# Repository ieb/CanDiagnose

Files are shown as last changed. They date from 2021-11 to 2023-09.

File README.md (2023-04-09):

# Can Diagnose

Runs on a ESP32 with a webserver exposing an API to diagnose and monitor CanBus traffic.
Based on Datadisplay and DeviceAnalyser from the NMEA2000 libraries.

* [x] Setup Wifi
* [x] Setup MDNS registration
* [x] Implement webserver
* [x] Serve files from Flash (SPIFFS)
* [x] Implement data api /api/data/<n> where n == 0-10.
* [x] Expose set of standard CAN messages on /api/data
* [x] Implement simple UI in Javascript hosted on SPIFFS, targetting eink and normal browsers (based on SignalK eink)
* [x] Implement BPM280 source
* [x] Implement calibration mechanism using DAC
* [Fail] Implement ADC Source

The ESP32 ADC source cannot be made reliable enough or accurate enough to be used to monitor a battery. 
It is possible to get down to a 0.2% error with a callibrated lookup table, however the ADC mechamism (Sucessive Aproximation Register)
produced noisy values that are frequetly as much as +- 3%. At 12.6v this is 0.4v which is unworkable. Offsetting the voltage with a precision opamp so the ESP32 reads from 11 to 15v would reduce this to 0.15v, however this is still to large to be usable. Multi sampling helps generate a stable reading, however this requires 64 samples with a /5 moving average so over at least 60s. This does give and acceptable accuracy, but the speed of measuring the voltage is close to unworkable.

All attenuations were tried, and 1,2,4,16,32,64 clock divisions were tried to see if the rate of the SAR made any difference. It does not appear to change the results.

On that basis, I am giving up on using the ESP32 ADC for this purpose.

It still provides a good platform for a Wifi data server, and Can reader.

* [x] Redesign PCB to use 16bit ADC over i2c  (ADS1115)
* [x] Implement ADC sensor code.  
* [x] Implement admin interface.
* [x] Support configuration and calibration via web browser.
* [x] Support Configuraiton of single and differential ADC.
* [x] Add OLED display 
* [x] Add touch sensor to control oled display
* [x] Bench Calibrate expecialy shunt
* [x] Install test and calibrate. - Failed, the distance beween the board and the batteries is too great to get reliable shunt measurements.
* [x] Investigate using a shunt amplifier as used by VRA Alternator controll
* [x] Implement remote battery sensor using Modbus  (see BatterySensor project)
* [x] Reimplement PCB to have no BME280 and no ADS1115 replacing with a RS485 interface to ModBus devices.  (see CanPressure for Can based pressure, humidity, temperature sensor)
* [x] Implement Modbus master

# Usage

The device will boot and connect to wifi controlled by its burned in config file (data/config.txt). 
There are 2 modes it can run in, a WiFi client or a AP. If its configured to be an AP, then join its network. If its a client find its ip. From now on this will be <ip>

Go to its ip on http://<ip> and you will see a data view of the data it is capturing.
Go to http://<ip>/admin.html and you will see a admin view with the ability to upload a new configuration file and reboot.

Both these views ae SPAs served from static files burned into the ESP32 Flash using APIs.

Connecting to the serial port monitor allows lower level control and diagnostics, enter 'h<CR>' to get help.

# Developing

Project uses PlatformIO in VSCode.  WebUI is in  ui/einkweb with build files added to data/ to be built into a flash image using ./buidui.sh

## PIO commands

because I alwaysforget.

* pio run -t upload
* pio device monitor

See buildui.sh for SPIFFS image commands.

# Connectors

    ---------------------------------------------
    |           a b c d e f g h                 |
    |  A                                        |
    |  B                                        |
    |  C                                        |
    |  D                                     H  |
    |  E                                     I  |
    |  F                                     J  |
    |  G           i j k l m                 K  |
    ---------------------------------------------

    a  SPI BL   GPIO13
    b  SPI RST  GPIO12
    c  SPI DC   GPIO26
    d  SPI CS   GPIO25
    e  SPI SCK  GPIO33
    f  SPI MOSI GPIO32
    g  SPI GND  
    h  SPI 3V    
    i  i2c GND      Display black/blue
    j  i2c SCL  D5    Display green
    k  i2c SDA  D18    Display white
    l  i2c BTN  D19    Display yellow
    m  i2c 3V       Display red

    A  1wire 1w  D21
    B  1wire GND
    C  1wire 3V
    D  RS-485 5.8V
    E  RS-485 GND
    F  RS-485 A 
    G  RS-485 B
    H  CAN 12V
    I  CAN 0V
    J  CAN CANH
    K  CAN CANL

    Other Pins Not mentioned above
    RS485-TX TX2/GPIO17
    RS485-RX RX2/GPIO16
    RS485-EN D4
    CAN-RX  D22
    CAN-TX  D23

# eInk Waveshare display

This uses SPI output only with a bunch of additional pins.

    eInk DIN <-  f  SPI MOSI GPIO32
    eInk CLK <-  e  SPI SCK  GPIO33
    eInk CS  <-  d  SPI CS   GPIO25
    eInk DC  <-  c  SPI DC   GPIO26
    eInk RST <-  b  SPI RST  GPIO12
    eInk BUSY -> a  SPI BL   GPIO13

# 4 inch TFT display 480x320 24 bit colour driven by a ILI9488 driver.

uses SPI + a PWM blacklight. Control via a TPP233 Touch switch. Library is TFT_eSPI library. Pin mappings defined as compile definitions.

    -D TFT_MISO=GPIO_NUM_35
    -D TFT_MOSI=GPIO_NUM_32
    -D TFT_SCLK=GPIO_NUM_33
    -D TFT_CS=GPIO_NUM_25
    -D TFT_DC=GPIO_NUM_26
    -D TFT_RST=GPIO_NUM_27
    -D TFT_PWM_BL=GPIO_NUM_14
    -D ILI9488_DRIVER

The display sleeps after 60s of inactivity to reduce power drain, but turning off the backlight. Sleeping the IMI9488 driver has not been done as of yet.  Pages are implemented as classes using widgets. When a page is selected it is allocated into heap and does not exist while not displaying. On other drivers here all pages were compiled in, however the RAM usage is higher on account of full colour and display size. 

In most cases attempts to update the screen, on screen causes flickering so double buffering of updates is done using sprits with DMA transfers from the sprite to the screen. Images for screen are stored in jpg on flash, consuming about 30KB per screen.

Drawing to sprites also works in 1bpp, 4bpp or 16bpp.

## TFT case

3d printed case, with 2 touch sensors and round shielded cable, as ribbon will emit too much interference to nearby devices. 

Wires

|| color || designation || ESP32 Pin ||
---------------------------------------
| Red    |  5v          | 5v           |
| black  |  0v          | 0v           |
| pink   |  CS          | GPIO_NUM_25  |
| cyan   |  Reset       | GPIO_NUM_27  |
| white  |  DC/RS       | GPIO_NUM_26  |
| blue   |  SDI(MOSI)   | GPIO_NUM_32  |
| green  |  SCK         | GPIO_NUM_33  |
| grey   |  LED         | GPIO_NUM_14  |
| Purple |  SDO(MISO)   | GPIO_NUM_35  |
| Orange |  3.3v        | 3.3v         |
| Brown  | Touch Lower  | GPIO_NUM_19  |
| Yellow | Touch Top    | TBD          |

Due to the additional touch pins a fresh PCB is probably needed.

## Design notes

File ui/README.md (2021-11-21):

# UIs

Here are a variety of UIs that are burned into the firmware.
They all use the http API to fetch data from the ESP32 once loaded, defined in swagger.yaml in this directory.

# einkweb

Is a minimal eink browser implementation targetting Generation 1 Kindle devices, but also works on modern browsers and Andriod.

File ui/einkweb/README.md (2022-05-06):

# eink UI 

Based on the UI code used for Eink Signal K, but modified for this firmware and simplified.

# Current state

* Multiple pages
* Landscape and Portrate
* min, max, mean, standard deviation
* linear and circular stats
* Themes, night, day, red, green

# developing

Local server, run  npx http-server and use index_debug.html to load data from a running ESP32 device on the same network.

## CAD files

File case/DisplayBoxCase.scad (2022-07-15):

$fn=100;
module board() {
    difference() {
    union() {
        cube([75,59,3], center=true);
        translate([-32,-4,6])
        cube([8,41,12], center=true);
        translate([32,-12,6])
        cube([8,25,12], center=true);
        translate([0,14,8])
        cube([55,28,21], center=true);
        translate([20,-18,-8])
        cylinder(d=8,h=8);
    }
    translate([-(75/2)+4.5,-(59/2)+3,0])
    cylinder(d=4,h=10,center=true);
    translate([-(75/2)+6.2,(59/2)-6.5,0])
    cylinder(d=4,h=10,center=true);
    translate([(75/2)-4.6,(59/2)-4.7,0])
    cylinder(d=4,h=10,center=true);
    translate([(75/2)-4.6,-(59/2)+3.3,0])
    cylinder(d=4,h=10,center=true);
    }
}

module lid(w=110,d=70,h=15,hb=20,t=3) {
            translate([0,0,hb-t+1]) 
      difference() {
        union() {
            difference() {
                union() {
                    cube([w-t*2,d,h], center=true);
                    cube([w,d-t*2,h], center=true);
                    translate([w/2-t,d/2-t,0])
                    cylinder(r=t,h=h, center=true);
                    translate([-(w/2-t),d/2-t,0])
                    cylinder(r=t,h=h, center=true);
                    translate([-(w/2-t),-(d/2-t),0])
                    cylinder(r=t,h=h, center=true);
                    translate([w/2-t,-(d/2-t),0])
                    cylinder(r=t,h=h, center=true);
                    

                }
                // inside
                translate([0,0,-t*1.5])
                    cube([w-t*2,d-t*2,h+t], center=true);
            translate([0,0,-hb+t]) 
                cables();
            }
            // pillars
            translate([0,0,-hb+t]) {
            translate([-(75/2)+4.5,-(59/2)+3,0])
                union() {
                    cylinder(d=6,h=24);
                }
            translate([-(75/2)+6.2,(59/2)-6.5,0])
                union() {
                    cylinder(d=6,h=24);
                }
            translate([(75/2)-4.6,(59/2)-4.7,0])
                union() {
                    cylinder(d=6,h=24);
                }
            translate([(75/2)-4.6,-(59/2)+3.3,0])
                union() {
                    cylinder(d=6,h=24);
                }
            }
            // fxings
            translate([w/2-2*t,d/2-2*t,0])
                    cylinder(r=5,h=h, center=true);
            translate([-(w/2-2*t),d/2-2*t,0])
                    cylinder(r=5,h=h, center=true);
            translate([-(w/2-2*t),-(d/2-2*t),0])
                    cylinder(r=5,h=h, center=true);
                    translate([w/2-2*t,-(d/2-2*t),0])
                    cylinder(r=5,h=h, center=true);
        }
        
            translate([w/2-2*t,d/2-2*t,0])
                    cylinder(d=3,h=h+10, center=true);
            translate([-(w/2-2*t),d/2-2*t,0])
                    cylinder(d=3,h=h+10, center=true);
            translate([-(w/2-2*t),-(d/2-2*t),0])
                    cylinder(d=3,h=h+10, center=true);
                    translate([w/2-2*t,-(d/2-2*t),0])
                    cylinder(d=3,h=h+10, center=true);
    }
}

module case(w=110,d=70,h=20,t=3) {
      difference() {
        union() {
            difference() {
                union() {
                    cube([w-t*2,d,h], center=true);
                    cube([w,d-t*2,h], center=true);
                    translate([w/2-t,d/2-t,0])
                    cylinder(r=t,h=h, center=true);
                    translate([-(w/2-t),d/2-t,0])
                    cylinder(r=t,h=h, center=true);
                    translate([-(w/2-t),-(d/2-t),0])
                    cylinder(r=t,h=h, center=true);
                    translate([w/2-t,-(d/2-t),0])
                    cylinder(r=t,h=h, center=true);
                    

                }
                // inside
                translate([0,0,t])
                    cube([w-t*2,d-t*2,h+t], center=true);
                cables();
            }
            // pillars
            translate([0,0,-h/2+t/2]) {
            translate([-(75/2)+4.5,-(59/2)+3,0])
                union() {
                    cylinder(d=6,h=7);
                    cylinder(d=3,h=9);
                }
            translate([-(75/2)+6.2,(59/2)-6.5,0])
                union() {
                    cylinder(d=6,h=7);
                    cylinder(d=3,h=9);
                }
            translate([(75/2)-4.6,(59/2)-4.7,0])
                union() {
                    cylinder(d=6,h=7);
                    cylinder(d=3,h=9);
                }
            translate([(75/2)-4.6,-(59/2)+3.3,0])
                union() {
                    cylinder(d=6,h=7);
                    cylinder(d=3,h=9);
                }
            }
            // fxings
            translate([w/2-2*t,d/2-2*t,0])
                    cylinder(r=5,h=h, center=true);
            translate([-(w/2-2*t),d/2-2*t,0])
                    cylinder(r=5,h=h, center=true);
            translate([-(w/2-2*t),-(d/2-2*t),0])
                    cylinder(r=5,h=h, center=true);
                    translate([w/2-2*t,-(d/2-2*t),0])
                    cylinder(r=5,h=h, center=true);
        }
        
            translate([w/2-2*t,d/2-2*t,0])
                    cylinder(d=3,h=h+10, center=true);
            translate([-(w/2-2*t),d/2-2*t,0])
                    cylinder(d=3,h=h+10, center=true);
            translate([-(w/2-2*t),-(d/2-2*t),0])
                    cylinder(d=3,h=h+10, center=true);
                    translate([w/2-2*t,-(d/2-2*t),0])
                    cylinder(d=3,h=h+10, center=true);
    }

}
module cables() {
        translate([-90,-15,10])
    rotate([0,90,0])
    cylinder(d=4,h=90);
    translate([-90,15,10])
    rotate([0,90,0])
    cylinder(d=4,h=90);

    translate([-90,0,10])
    rotate([0,90,0])
    cylinder(d=4,h=90);

    translate([0,-15,10])
    rotate([0,90,0])
    cylinder(d=7,h=90);
}

/*
difference() {
    union() {
        //board();
        case();
        lid();
          //cables();
    }
    cube([65,160,140], center=true);
}
*/

case();
//replid();

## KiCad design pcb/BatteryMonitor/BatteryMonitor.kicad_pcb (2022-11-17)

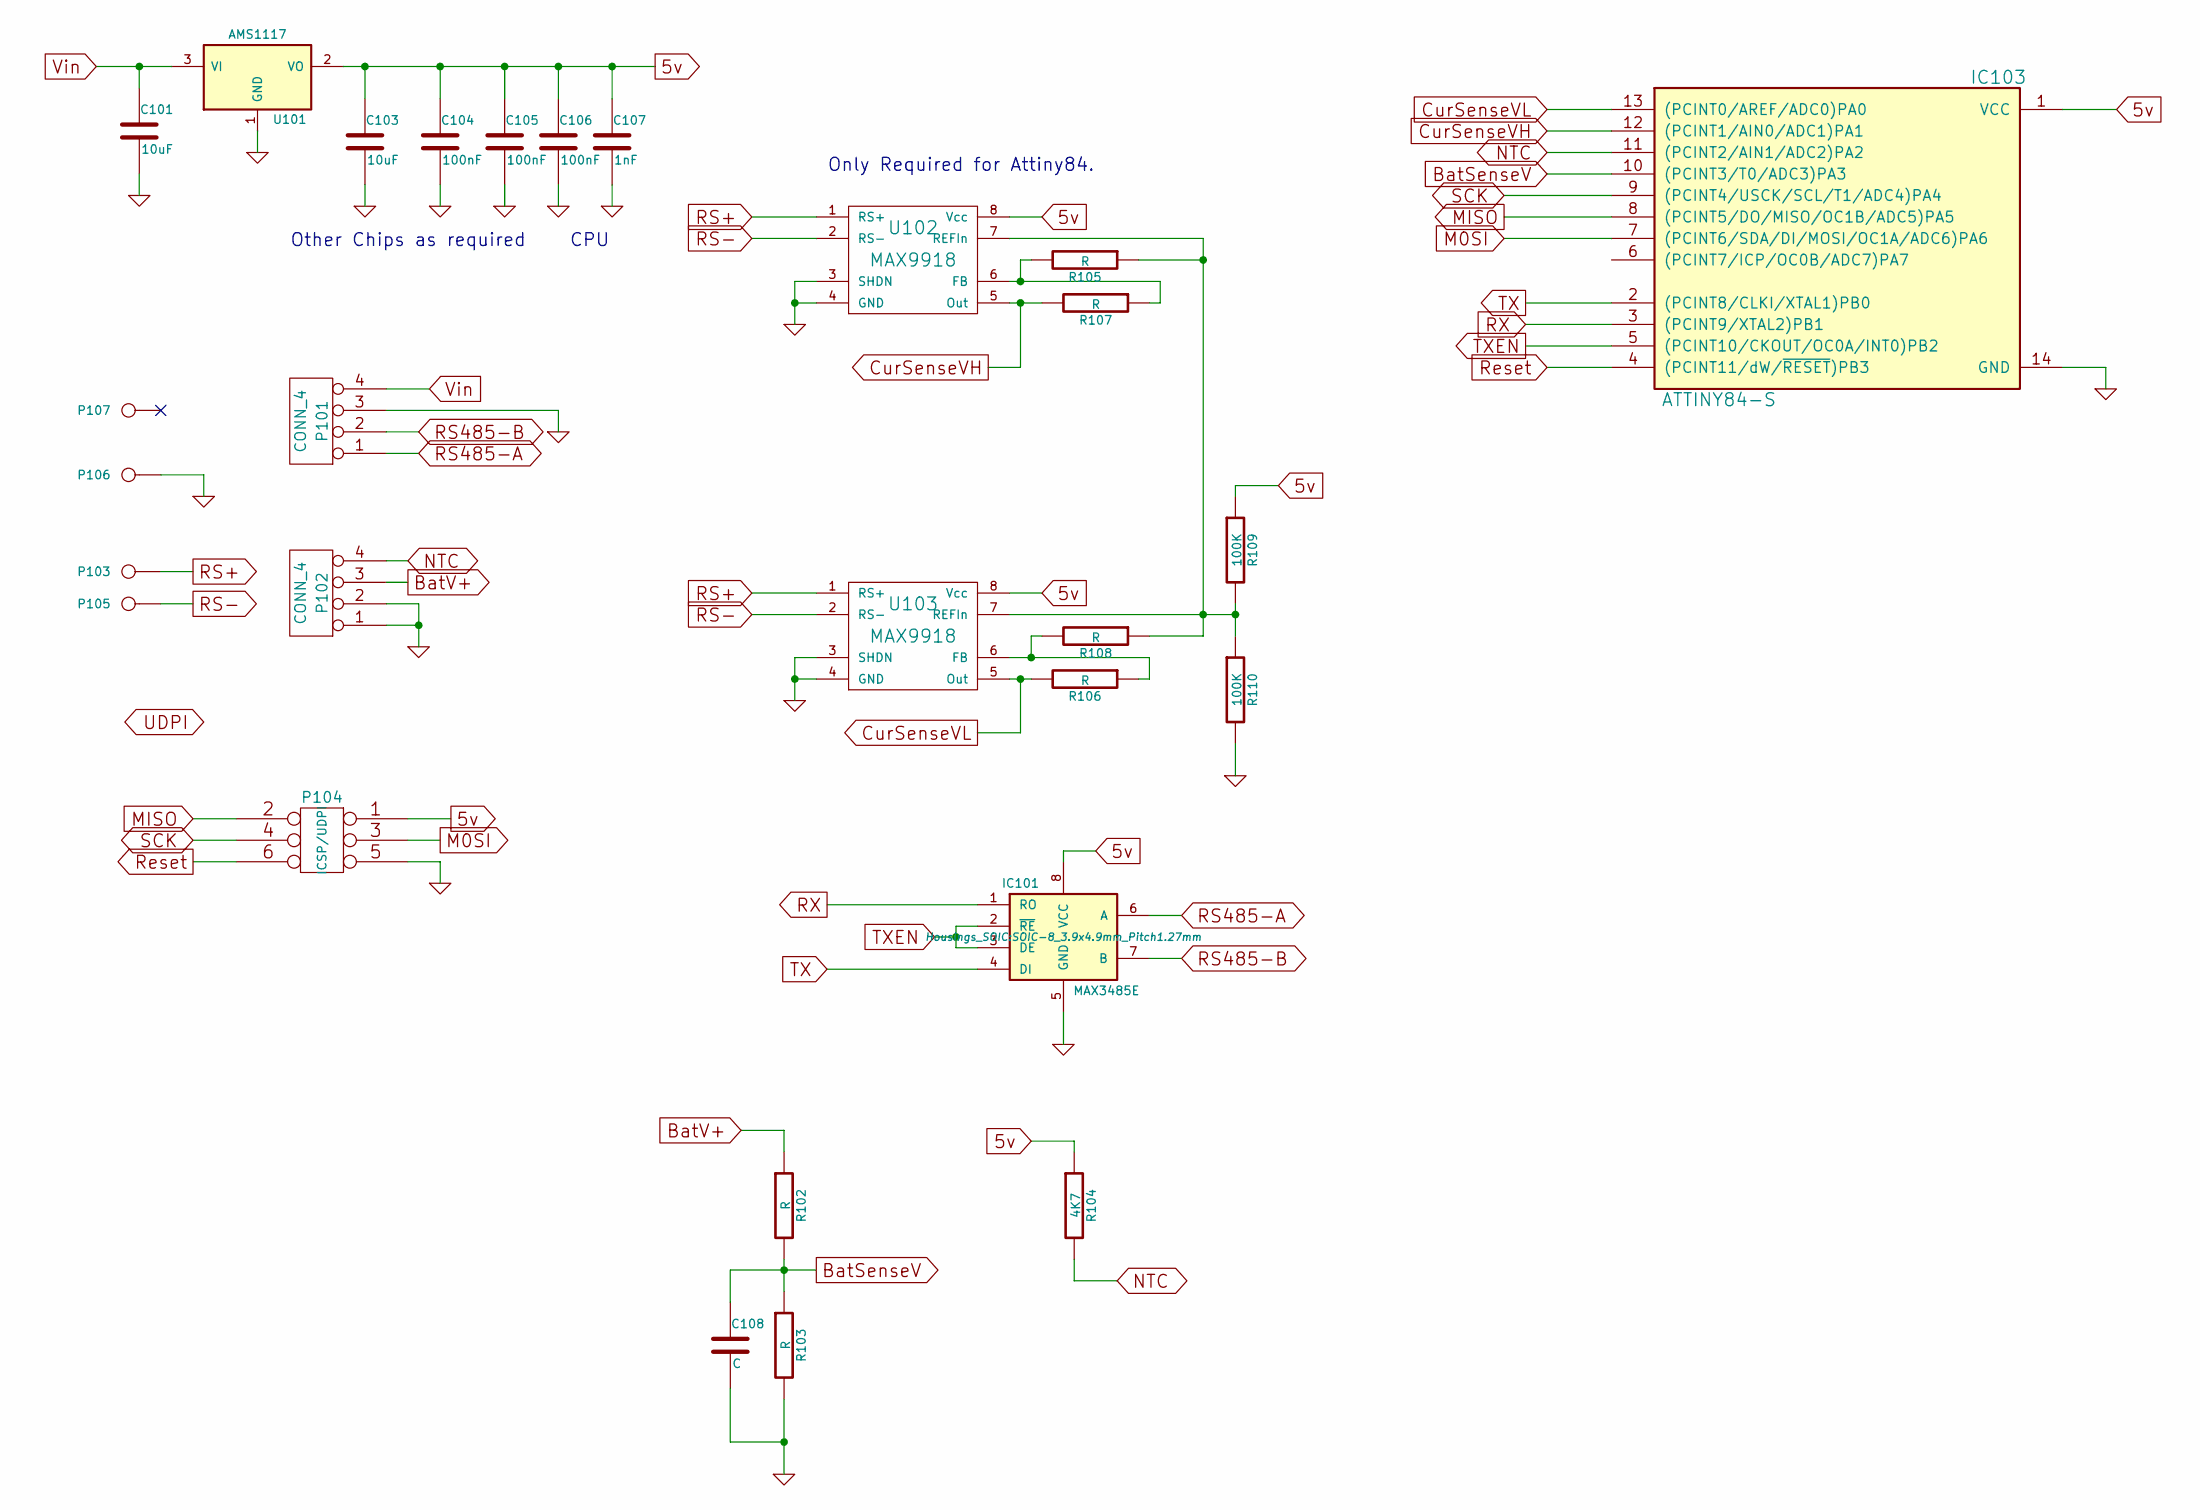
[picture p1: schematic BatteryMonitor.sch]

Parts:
C101, C103: 10uF; C_1206
C104, C105, C106: 100nF; C_0805
C107: 1nF; C_0805
C108: C; C_0805
IC101: MAX3485E; SOIC-8_3.9x4.9mm_Pitch1.27mm
IC103: ATTINY84-S; DIP-14_W7.62mm
P101, P102: CONN_4; bornier4
P103, P106, P107: RS+; 1pin
P104: ICSP/UDPI; Pin_Header_Straight_2x03
P105: RS-; 1pin
R102, R103, R105, R106, R107, R108: R; R_0805
R104: 4K7; R_0805
R109, R110: 100K; R_0805
U101: AMS1117; SOT-223-3Lead_TabPin2
U102, U103: MAX9918; SOIC-8_3.9x4.9mm_Pitch1.27mm

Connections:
5v: C103.1, C104.1, C105.1, C106.1, C107.1, IC101.8 (VCC), IC103.1 (VCC), P104.1, R104.1, R109.1, U101.2 (VO), U102.8 (Vcc), U103.8 (Vcc)
BatSenseV: C108.1, IC103.10 ((PCINT3/T0/ADC3)PA3), R102.2, R103.1
BatV+: P102.3, R102.1
CurSenseVH: IC103.12 ((PCINT1/AIN0/ADC1)PA1), R107.2, U102.5 (Out)
CurSenseVL: IC103.13 ((PCINT0/AREF/ADC0)PA0), R106.2, U103.5 (Out)
GND: C101.2, C103.2, C104.2, C105.2, C106.2, C107.2, C108.2, IC101.5 (GND), IC103.14 (GND), P101.3, P102.1, P102.2, P104.5, P106.1, R103.2, R110.2, U101.1 (GND), U102.3 (SHDN), U102.4 (GND), U103.3 (SHDN), U103.4 (GND)
M0SI: IC103.7 ((PCINT6/SDA/DI/MOSI/OC1A/ADC6)PA6), P104.3
MISO: IC103.8 ((PCINT5/DO/MISO/OC1B/ADC5)PA5), P104.2
NTC: IC103.11 ((PCINT2/AIN1/ADC2)PA2), P102.4, R104.2
unnamed: R105.1, R108.1, R109.2, R110.1, U102.7 (REFIn), U103.7 (REFIn)
unnamed: R105.2, R107.1, U102.6 (FB)
unnamed: R106.1, R108.2, U103.6 (FB)
RS485-A: IC101.6 (A), P101.1
RS485-B: IC101.7 (B), P101.2
RS+: P103.1, U102.1 (RS+), U103.1 (RS+)
RS-: P105.1, U102.2 (RS-), U103.2 (RS-)
RX: IC101.1 (RO), IC103.3 ((PCINT9/XTAL2)PB1)
Reset: IC103.4 ((PCINT11/dW/~RESET~)PB3), P104.6
SCK: IC103.9 ((PCINT4/USCK/SCL/T1/ADC4)PA4), P104.4
TX: IC101.4 (DI), IC103.2 ((PCINT8/CLKI/XTAL1)PB0)
TXEN: IC101.2 (~RE~), IC101.3 (DE), IC103.5 ((PCINT10/CKOUT/OC0A/INT0)PB2)
Vin: C101.1, P101.4, U101.3 (VI)

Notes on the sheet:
Only Required for Attiny84.
CPU
Other Chips as required

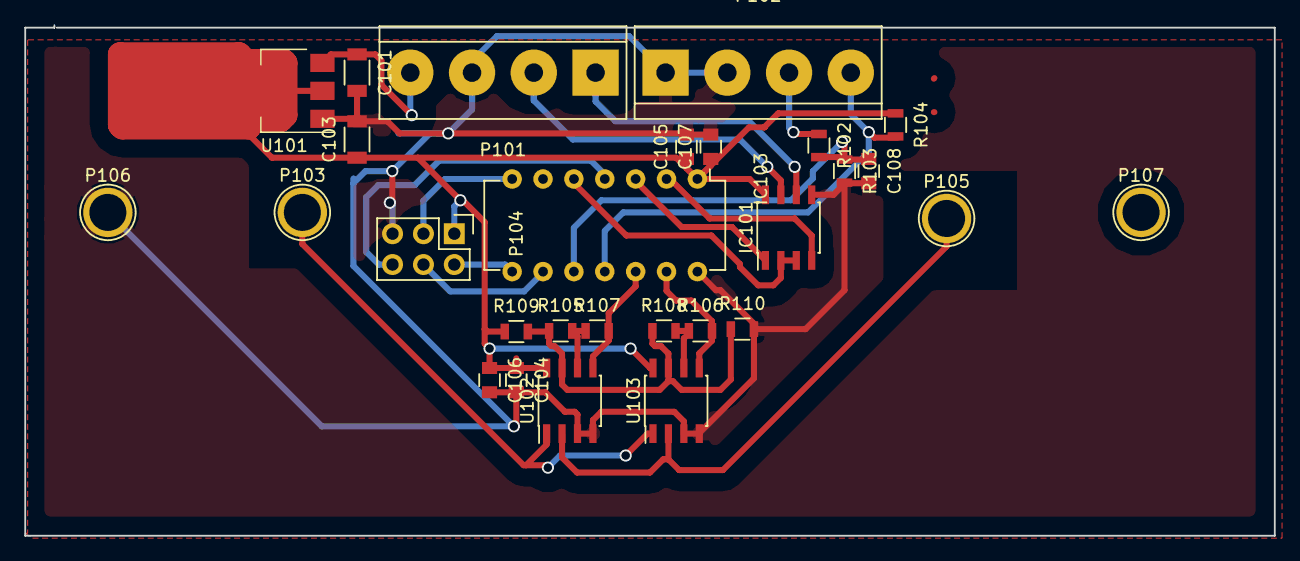
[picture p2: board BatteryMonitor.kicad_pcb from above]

Board: 2 copper layers, 102.8 x 42.0 mm, 28 parts (0 on the bottom side), 22 nets.

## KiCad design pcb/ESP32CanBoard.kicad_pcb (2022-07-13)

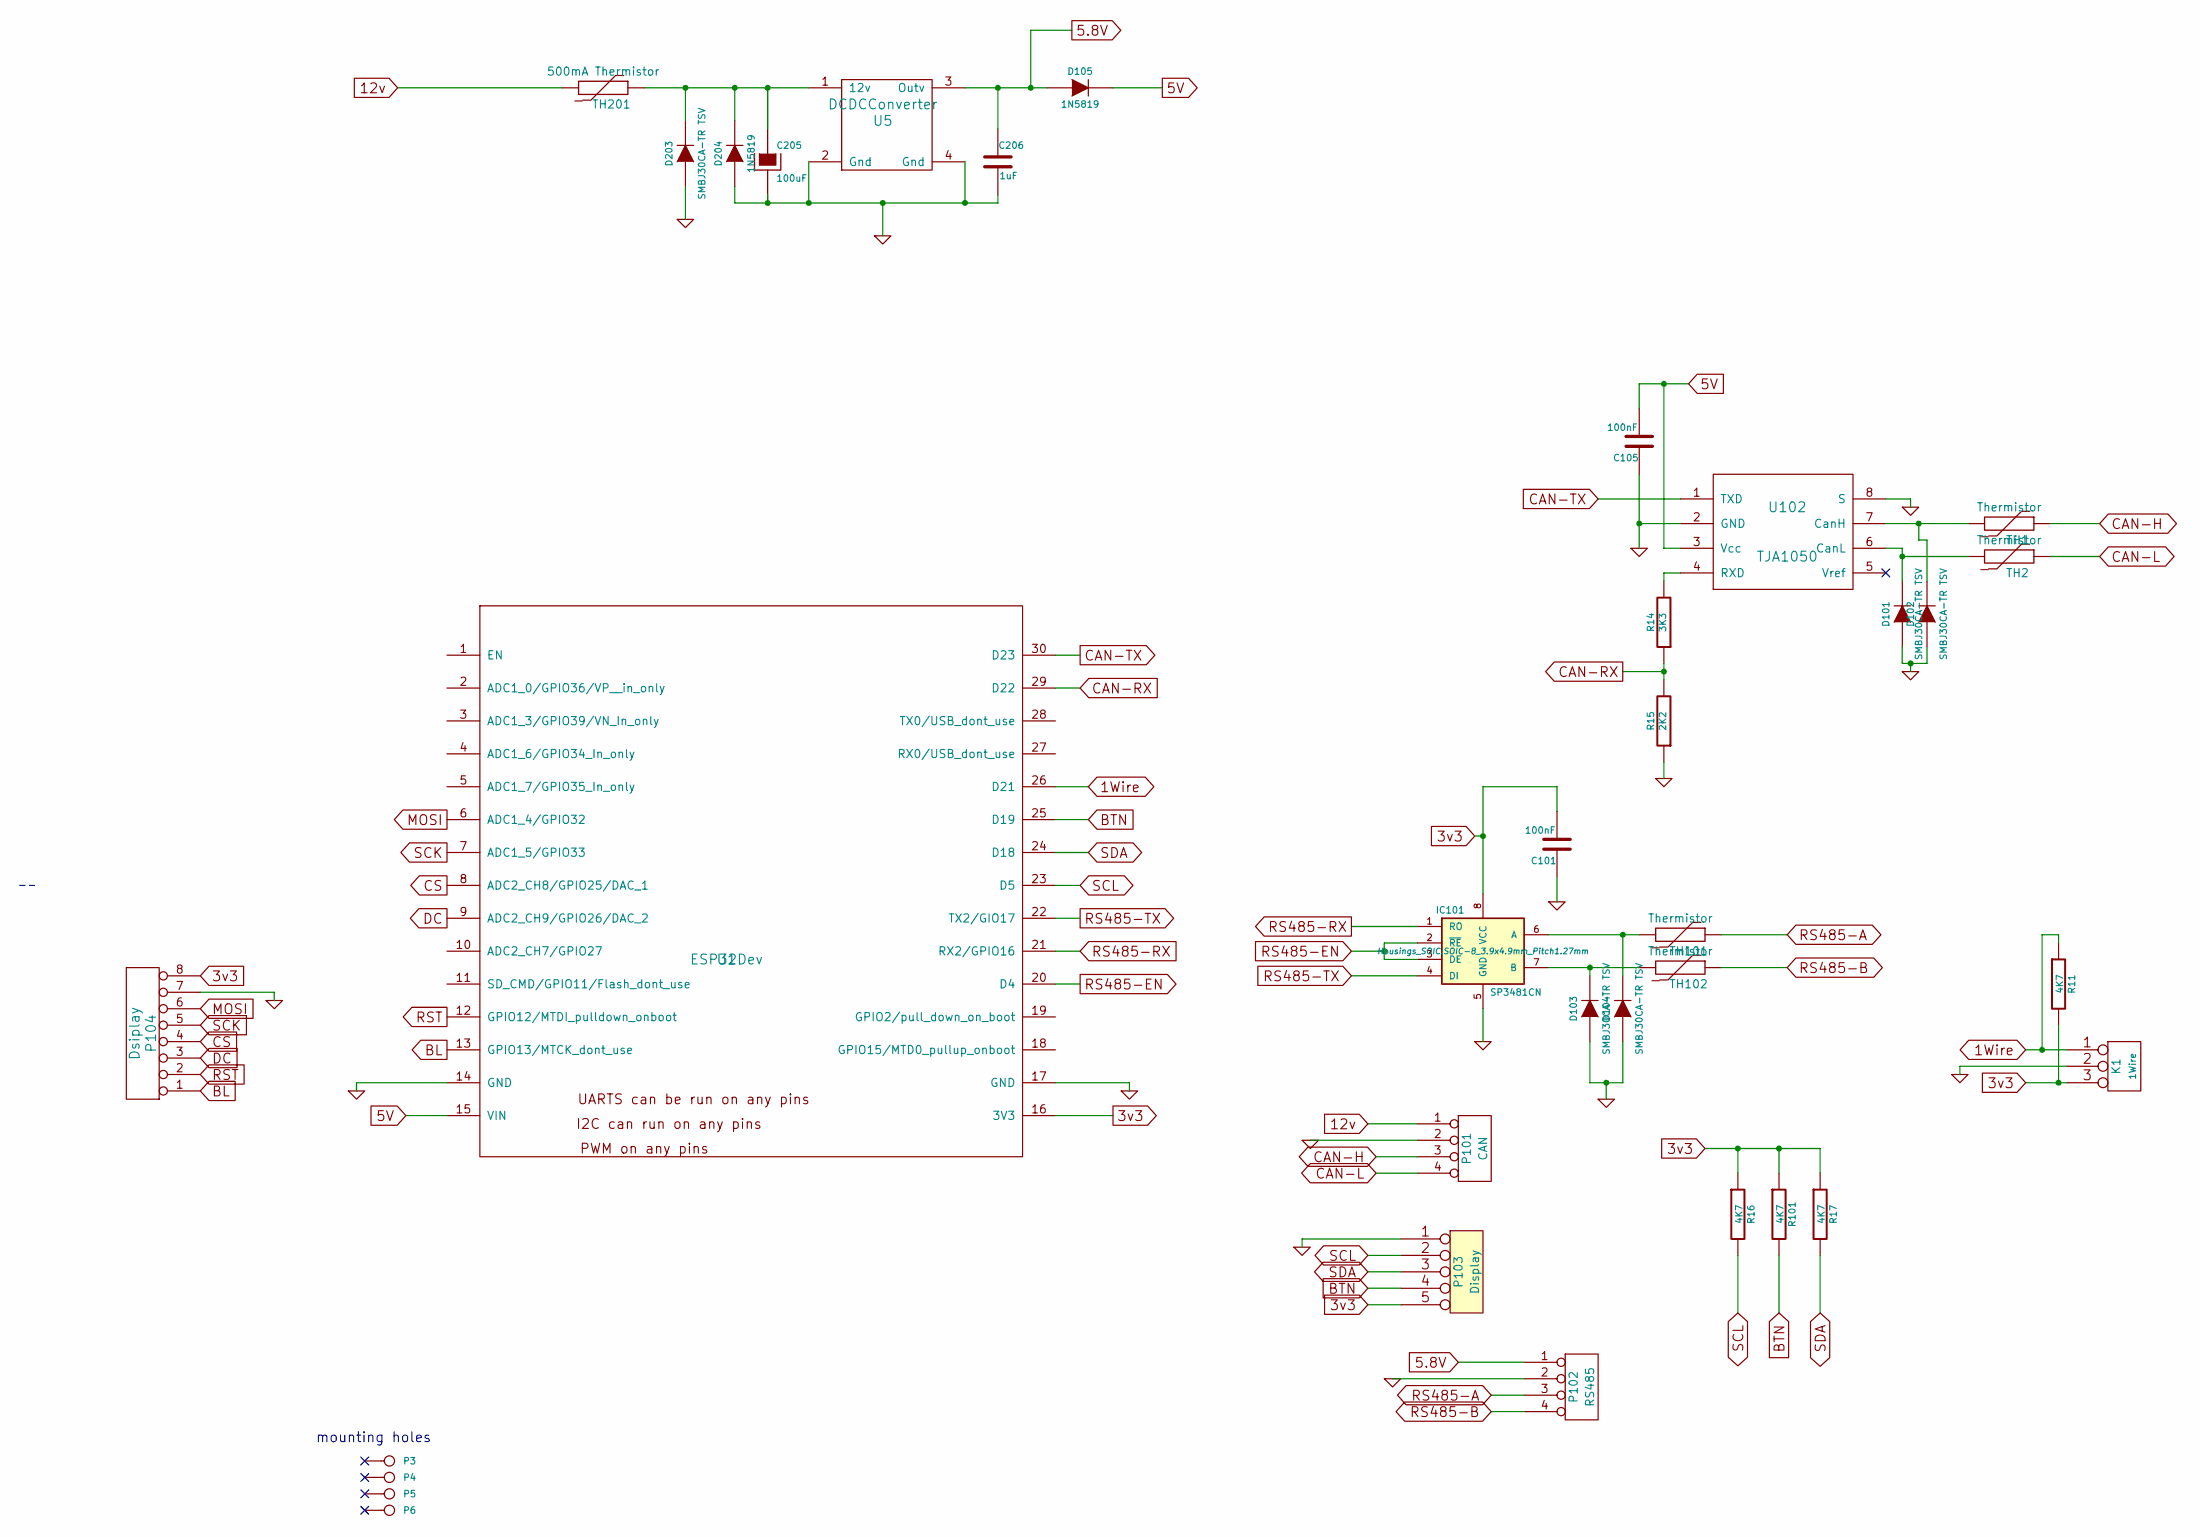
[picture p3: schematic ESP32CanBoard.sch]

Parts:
C101, C105: 100nF; C_0805
C205: 100uF; C_1210
C206: 1uF; C_1210
D101, D102, D103, D104, D203: SMBJ30CA-TR TSV; DO-214AB
D105, D204: 1N5819; D_1206
IC101: SP3481CN; SOIC-8_3.9x4.9mm_Pitch1.27mm
K1: 1Wire; bornier3
P3, P4, P5, P6: CONN_1; 1pin
P101: CAN; bornier4
P102: RS485; bornier4
P103: Display; Pin_Header_Straight_1x05
P104: Dsiplay; Pin_Header_Straight_1x08
R11, R16, R17, R101: 4K7; R_0805
R14: 3K3; R_0805
R15: 2K2; R_0805
TH1, TH2, TH101, TH102: Thermistor; R_1812
TH201: 500mA Thermistor; Resistor_Horizontal_RM7mm
U1: ESP32Dev
U5: DCDCConverter; DC-DC-Converter
U102: TJA1050; SOIC-8_3.9x4.9mm_Pitch1.27mm

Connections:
1Wire: K1.1, R11.1, U1.26 (D21)
3v3: C101.2, IC101.8 (VCC), K1.3, P103.5, P104.8, R11.2, R16.1, R17.1, R101.1, U1.16 (3V3)
5.8V: C206.1, D105.1 (A), P102.1, U5.3 (Outv)
5V: C105.2, D105.2 (K), U1.15 (VIN), U102.3 (Vcc)
12v: P101.1, TH201.2
BL: P104.1, U1.13 (GPIO13/MTCK_dont_use)
BTN: P103.4, R101.2, U1.25 (D19)
CAN-H: P101.3, TH1.1
CAN-L: P101.4, TH2.1
CAN-RX: R14.1, R15.2, U1.29 (D22)
CAN-TX: U1.30 (D23), U102.1 (TXD)
CS: P104.4, U1.8 (ADC2_CH8/GPIO25/DAC_1)
DC: P104.3, U1.9 (ADC2_CH9/GPIO26/DAC_2)
GND: C101.1, C105.1, C205.2, C206.2, D101.1 (A), D102.1 (A), D103.1 (A), D104.1 (A), D203.1 (A), D204.1 (A), IC101.5 (GND), K1.2 (PM), P101.2, P102.2, P103.1, P104.7, R15.1, U1.14 (GND), U1.17 (GND), U5.2 (Gnd), U5.4 (Gnd), U102.2 (GND), U102.8 (S)
MOSI: P104.6, U1.6 (ADC1_4/GPIO32)
unnamed: C205.1, D203.2 (K), D204.2 (K), TH201.1, U5.1 (12v)
unnamed: D101.2 (K), TH2.2, U102.6 (CanL)
unnamed: D102.2 (K), TH1.2, U102.7 (CanH)
unnamed: D103.2 (K), IC101.7 (B), TH102.2
unnamed: D104.2 (K), IC101.6 (A), TH101.2
unnamed: R14.2, U102.4 (RXD)
RS485-A: P102.3, TH101.1
RS485-B: P102.4, TH102.1
RS485-EN: IC101.2 (~RE~), IC101.3 (DE), U1.20 (D4)
RS485-RX: IC101.1 (RO), U1.21 (RX2/GPIO16)
RS485-TX: IC101.4 (DI), U1.22 (TX2/GIO17)
RST: P104.2, U1.12 (GPIO12/MTDI_pulldown_onboot)
SCK: P104.5, U1.7 (ADC1_5/GPIO33)
SCL: P103.2, R16.2, U1.23 (D5)
SDA: P103.3, R17.2, U1.24 (D18)

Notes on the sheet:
mounting holes

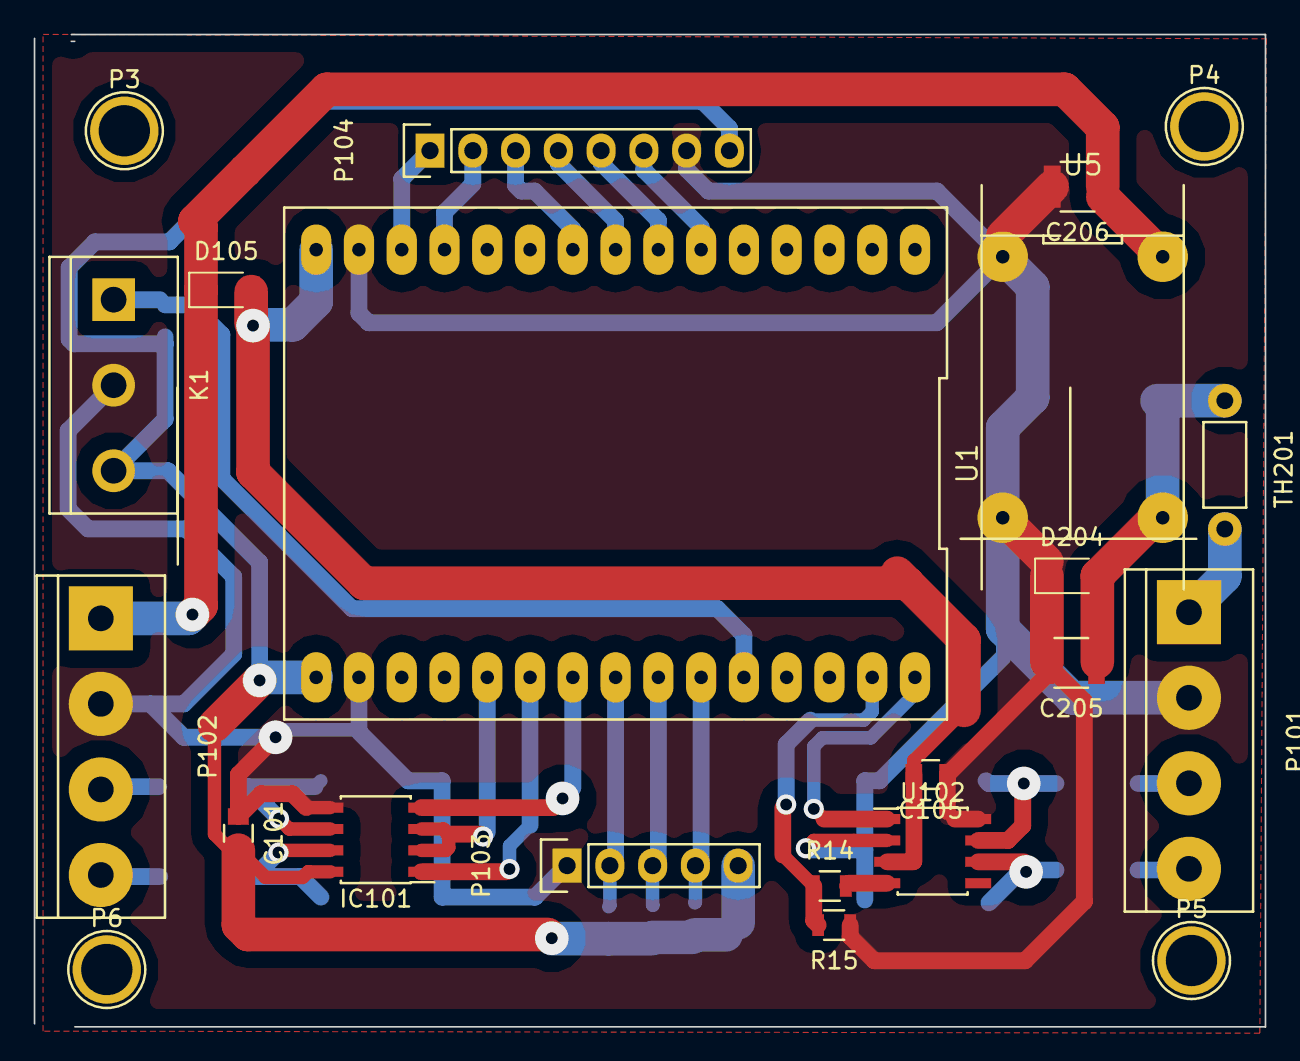
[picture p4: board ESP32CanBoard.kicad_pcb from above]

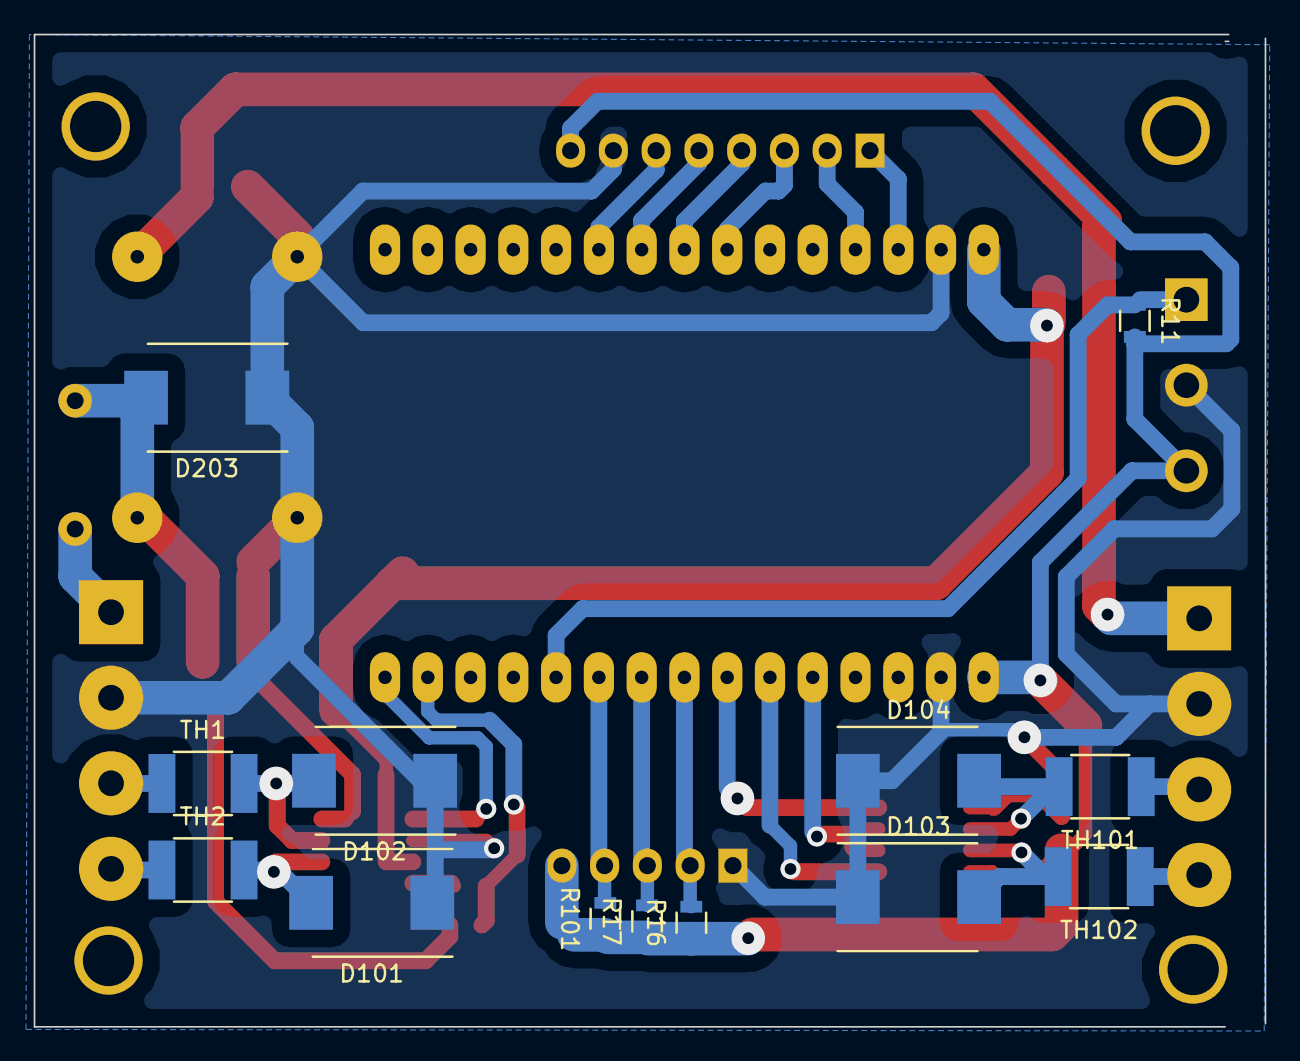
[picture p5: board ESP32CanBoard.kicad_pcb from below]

Board: 2 copper layers, 73.1 x 58.9 mm, 35 parts (13 on the bottom side), 30 nets.

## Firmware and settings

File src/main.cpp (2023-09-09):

// Demo: NMEA2000 library. 
// This demo reads messages from NMEA 2000 bus and
// sends them translated to clear text to Serial.

// Note! If you use this on Arduino Mega, I prefer to also connect interrupt line
// for MCP2515 and define N2k_CAN_INT_PIN to related line. E.g. MessageSender
// sends so many messages that Mega can not handle them. If you only use
// received messages internally without slow operations, then youmay survive
// without interrupt.

#include <Arduino.h>
#include <Wire.h>



// Pins   
#define ESP32_CAN_RX_PIN GPIO_NUM_22
#define ESP32_CAN_TX_PIN GPIO_NUM_23
#define ONEWIRE_GPIO_PIN GPIO_NUM_21
#define SDA_PIN GPIO_NUM_18
#define SCL_PIN GPIO_NUM_5
#define DISPLAY_BUTTON GPIO_NUM_34

// RS584 on Serial2 TX
#define RS485_TX GPIO_NUM_17
#define RS485_RX GPIO_NUM_16
#define RS485_EN GPIO_NUM_4



// Calibrations to take account of resistor tollerances, this is specific to the board being flashed.
// should probably be in a config file eventually.



#include <NMEA2000_esp32.h>

// The method recomended doesnt work well so explicitly create the NMEA2000 objects to be sure
// the pins are correct. I've had loads of problems with this depening 
// on how the libraries are created.

tNMEA2000 &NMEA2000=*(new tNMEA2000_esp32(ESP32_CAN_TX_PIN, ESP32_CAN_RX_PIN));


// #include <NMEA2000_CAN.h>

#include "listdevices.h"
#include "N2KCollector.h"
#include "N2KPrinter.h"
#include "httpserver.h"
#include "temperature.h"
#include "logbook.h"
#include "modbus.h"
#include "dataoutput.h"

// Display implementions
#include "display.h"
//#include "einkdisplay.h"
//#include "OLEDDisplay.h"
#include "TFTDisplay.h"

#include "esp32-hal-psram.h"

// select one
//#define DISPLAY_MODULE OledDisplay
//#define DISPLAY_MODULE EinkDisplay
#define DISPLAY_MODULE TFTDisplay

//#define DISPLAY_MODULE NullDisplay




// Only define this if the main loop os so slow that 
// button presses dont work properly.
// #define USE_INTERRUPT 1

Stream *OutputStream = &Serial;
N2KPrinter n2kPrinter(OutputStream);
N2KCollector n2kCollector(OutputStream);
ListDevices listDevices(&NMEA2000, OutputStream);
EngineDataOutput engineDataOutput(n2kCollector);
BoatDataOutput boatDataOutput(n2kCollector);
NavigationDataOutput navigationDataOutput(n2kCollector);
EnvironmentDataOutput environmentDataOutput(n2kCollector);
TemperatureDataOutput temperatureDataOutput(n2kCollector);
XteDataOutput xteDataOutput(n2kCollector);
MagneticVariationDataOutput magneticVariationDataOutput(n2kCollector);
WindSpeedDataOutput windSpeedDataOutput(n2kCollector);
LogDataOutput logDataOutput(n2kCollector);
LatLonDataOutput latLonDataOutput(n2kCollector);
LeewayDataOutput leewayDataOutput(n2kCollector);


Temperature temperature(&NMEA2000, ONEWIRE_GPIO_PIN);


ModbusMaster modbusMaster(&Serial2, RS485_EN);
Modbus modbus(&NMEA2000, modbusMaster);


LogBook logbook(n2kCollector);


WebServer webServer(OutputStream);




TFT_eSPI tftDisplayDriver = TFT_eSPI();
TFTDisplay display(n2kCollector, modbus, webServer, tftDisplayDriver);

unsigned long lastButtonPress = 0;
unsigned long lastButtonRelease = 0;



void HandleNMEA2000Msg(const tN2kMsg &N2kMsg) {
    listDevices.HandleMsg(N2kMsg);
    n2kPrinter.HandleMsg(N2kMsg);
    n2kCollector.HandleMsg(N2kMsg);
}

void showHelp() {
  OutputStream->println("Device analyzer started.");
  OutputStream->println("  - Analyzer will automatically print new list on list changes.");
  OutputStream->println("  - Send 'h' to show this message");
  OutputStream->println("  - Send 's' to show status");
  OutputStream->println("  - Send 'u' to print latest list of devices");
  OutputStream->println("  - Send 'o' to toggle output, can be high volume");
  OutputStream->println("  - Send 'd' to toggle packet dump, can be high volume");
  OutputStream->println("  - Send 'm' to toggle modbus diagnostics");
  OutputStream->println("  - Send 'b' to change brightness");
  OutputStream->println("  - Send 'S' to put to sleep");
   
}



void setup() {
  Serial.begin(115200); 
  Serial2.begin(9600, SERIAL_8N1, RS485_RX, RS485_TX); // RS485 Modbus
  if ( !psramInit() ) {
    Serial.println("PSRAM not available.");
  } else {
    Serial.print("Total PSRAM: ");Serial.println(ESP.getPsramSize());
    Serial.print("Free PSRAM:  ");Serial.println(ESP.getFreePsram());
  }
  modbusMaster.begin();

  display.begin();
  display.update(0);
  display.setBacklightLevel(16);

  if (!Wire.begin(SDA_PIN, SCL_PIN) ) {
    Serial.println("I2C failed to start");
  } else {
    Serial.println("I2C scanning ");
    for (uint8_t addr = 0; addr < 255; addr++) {
        Wire.beginTransmission(addr);
        if (Wire.endTransmission() == 0) {
            Serial.print(" ");
            Serial.print(addr,HEX);
        } else {
            Serial.print(" --");
        }
        display.setBacklightLevel(16+addr/2);
    }
    Serial.println("Done ");
  }
  display.setBacklightLevel(144);

  display.update("I2C scanned",0);







  pinMode(DISPLAY_BUTTON, INPUT_PULLUP);

  temperature.begin();
  display.setBacklightLevel(160);
  modbus.begin();
  display.setBacklightLevel(176);

  display.update("Sensors started",1);
 
  webServer.addJsonOutputHandler(0,&listDevices);
  webServer.addJsonOutputHandler(1,&engineDataOutput);
  webServer.addJsonOutputHandler(2,&boatDataOutput);
  webServer.addJsonOutputHandler(3,&navigationDataOutput);
  webServer.addJsonOutputHandler(4,&environmentDataOutput);
  webServer.addJsonOutputHandler(5,&temperatureDataOutput);
  webServer.addJsonOutputHandler(6,&temperature);  
  webServer.addJsonOutputHandler(8,&modbus);
  webServer.addJsonOutputHandler(9,&xteDataOutput);  
  webServer.addJsonOutputHandler(10,&magneticVariationDataOutput);  
  webServer.addJsonOutputHandler(11,&logDataOutput);  
  webServer.addJsonOutputHandler(12,&latLonDataOutput);  
  webServer.addJsonOutputHandler(13,&leewayDataOutput);  

  webServer.addCsvOutputHandler(0,&listDevices);
  webServer.addCsvOutputHandler(1,&engineDataOutput);
  webServer.addCsvOutputHandler(2,&boatDataOutput);
  webServer.addCsvOutputHandler(3,&navigationDataOutput);
  webServer.addCsvOutputHandler(4,&environmentDataOutput);
  webServer.addCsvOutputHandler(5,&temperatureDataOutput);
  webServer.addCsvOutputHandler(6,&temperature);  
  webServer.addCsvOutputHandler(6,&modbus);  
  webServer.addCsvOutputHandler(9,&xteDataOutput);  
  webServer.addCsvOutputHandler(10,&magneticVariationDataOutput);  
  webServer.addCsvOutputHandler(11,&logDataOutput);  
  webServer.addCsvOutputHandler(12,&latLonDataOutput);  
  webServer.addCsvOutputHandler(13,&leewayDataOutput);  
  webServer.begin();
  display.setBacklightLevel(192);

  display.update("Web server started",2);

  // Set Product information
  NMEA2000.SetProductInformation("00000003", // Manufacturer's Model SerialIO code
                                 100, // Manufacturer's product code
                                 "N2k bus device analyzer",  // Manufacturer's Model ID
                                 "1.0.0.10 (2017-07-29)",  // Manufacturer's Software version code
                                 "1.0.0.0 (2017-07-12)" // Manufacturer's Model version
                                );

  // Set device information
  NMEA2000.SetDeviceInformation(5, // Unique number. Use e.g. SerialIO number.
                                130, // Device function=Display. See codes on http://www.nmea.org/Assets/20120726%20nmea%202000%20class%20&%20function%20codes%20v%202.00.pdf
                                120, // Device class=Display. See codes on  http://www.nmea.org/Assets/20120726%20nmea%202000%20class%20&%20function%20codes%20v%202.00.pdf
                                2046 // Just choosen free from code list on http://www.nmea.org/Assets/20121020%20nmea%202000%20registration%20list.pdf
                               );


//  NMEA2000.SetN2kCANReceiveFrameBufSize(50);
  // Do not forward bus messages at all
  NMEA2000.SetForwardType(tNMEA2000::fwdt_Text);
  NMEA2000.SetForwardStream(OutputStream);
  // Set false below, if you do not want to see messages parsed to HEX withing library
  NMEA2000.EnableForward(false);
  NMEA2000.SetN2kCANReceiveFrameBufSize(150);
  NMEA2000.SetN2kCANMsgBufSize(8);

  NMEA2000.SetMsgHandler(HandleNMEA2000Msg);

  NMEA2000.SetMode(tNMEA2000::N2km_ListenAndNode, 50);
  display.setBacklightLevel(208);
  NMEA2000.Open();
  display.update("NMEA2000 started",3);

  OutputStream->print("Running...");
  display.setBacklightLevel(224);
  showHelp();

  
}

//*****************************************************************************

void showStatus() {
  modbus.readStats();
  Serial.print("Total heap:  ");Serial.println(ESP.getHeapSize());
  Serial.print("Free heap:   ");Serial.println(ESP.getFreeHeap());
  // ESP32-WROOM chips which are common dont have PSRAM. 
  // ESP32-WRover do. See https://en.wikipedia.org/wiki/ESP32
  Serial.print("Has PSRAM:");Serial.println(psramFound());
  Serial.print("Total PSRAM: ");Serial.println(ESP.getPsramSize());
  Serial.print("Free PSRAM:  ");Serial.println(ESP.getFreePsram());
}

//*****************************************************************************
//NMEA 2000 message handler - should  be in a class so it can be attached.

//=================================================
// Diagnosis Functions and control

//*****************************************************************************

//*****************************************************************************
void CheckCommand() {
  static bool enableForward = false;
  static bool modbusDiagnose = false;
  if (OutputStream->available()) {
    char chr = OutputStream->read();
    switch ( chr ) {
      case 'h': showHelp(); break;
      case 'u': listDevices.list(true); break;
      case 's':
        showStatus();
        break;
      case 'o': 
        n2kPrinter.showData = !n2kPrinter.showData;
        if (  n2kPrinter.showData ) {
          Serial.println("Data Output Enabled");   
        } else {
          Serial.println("Data Output Disabled");   
        }
        break;
      case 'd': 
        enableForward = !enableForward;
        if (  enableForward ) {
          Serial.println("NMEA2000 Packet Output Enabled");   
        } else {
          Serial.println("NMEA2000 Packet Output Disabled");   
        }
        NMEA2000.EnableForward(enableForward); 
        break;
      case 'm':
        modbusDiagnose = !modbusDiagnose;
        if (  modbusDiagnose ) {
          Serial.println("Modbus Diagnostics enabled");   
        } else {
          Serial.println("Modbus Diagnostics disabled");   
        }
        modbus.setDiagnostics(modbusDiagnose);
        break;

      case 'b': 

        display.incTargetBrightness();
        break;
      case 'S':
        lastButtonPress = lastButtonRelease =  millis()-60000;
        break;
    }
  }
}

/*
void onPress() {
  display.nextPage();
}
void onLongRelease() {
  display.endDim();
}
void onLongPress() {
  display.startDim();
}

long checkPress() {
  static bool  pressed = false;
  static uint8_t bits = 0;
  static unsigned long lastCalled = 0, startPress = 0;
  unsigned long now = millis();


  // called every 100ms
  if ( now > lastCalled+10) {
    lastCalled = now;

    int dr = digitalRead(DISPLAY_BUTTON);
    if (  dr == HIGH ) {
      bits = bits<<1 & 0xfe;
    } else {
      bits = bits<<1 | 1;
    }
    // count the bits

    // Serial.println(bits,BIN);

    if (pressed && ((bits&0b00000111) == 0)  ) {
      // released for the last 150ms
      pressed = false;
      if ( now > (startPress+3000) ) {
        onLongRelease();
      } else {
        onPress();
      }
    } else if ( !pressed && ((bits&0b00000111) == 0b00000111) ) {
      // touched for the last 300ms
      pressed = true;
      startPress = now;
    } 
    if ( pressed && (now > (startPress+3000))) {
      onLongPress();
    }
  }
  return startPress; 
}
*/

/*
bool checkTouch() {
  static bool beingTouched = false;
  static unsigned long lastChange = 0;
  int touchValue = touchRead(Touch2);

  unsigned long now = millis();
  int8_t retValue = 0;
  if ( now-lastChange < 100) {
    // ignore
  } else if ( beingTouched ) {
    if (touchValue > TOUCH_THRESHOLD ) {
      beingTouched = false;
      lastChange = now;
    }
  } else {
    if (touchValue < TOUCH_THRESHOLD ) {
      beingTouched = true;
      lastChange = now;
      return true;
    }
  }
  return false;
}
*/


#ifndef USE_INTERRUPT


bool checkPress() {
  static bool beingPressed = false;
  static unsigned long lastBtnChange = 0;
  int dr = digitalRead(DISPLAY_BUTTON);
  unsigned long now = millis();
  if ( now-lastBtnChange < 100) {
    // ignore
  } else if ( beingPressed ) {
    if ( dr == LOW ) {
      beingPressed = false;
      lastBtnChange = now;
      lastButtonPress = now;      
    }
  } else {
    if ( dr == HIGH ) {
      beingPressed = true;
      lastBtnChange = now;
      lastButtonRelease = now;
      return true;
    }
  }
  return false;
}
#endif

unsigned long start = 0;
const char *timerMessages[9] = {
"NMEA2000.ParseMessages",
"temperature.read",
"temperature.output",
"modbus.read",
"modbus.output",
"logbook.log",
"CheckCommand",
"checkPress",
"display.update"  
};
int16_t totalCalls = 0;
unsigned long lastPrint = 0;
unsigned long counters[9] = {0,0,0,0,0,0,0,0,0};
uint16_t calls[9] = {0,0,0,0,0,0,0,0,0};
void startTimer() {
  start = millis();
}
void endTimer(int i) {
  unsigned long end = millis();
  calls[i]++;
  totalCalls++;
  counters[i] = counters[i]+(end-start);
  if ( end-lastPrint > (+10000) ) {
    lastPrint = end;
    Serial.print(end);
    Serial.print(" times:");
    for(int i = 0; i < 9; i++ ) {
      Serial.print(",");
      if (calls[i] == 0) {
        Serial.print("-");
      } else {
        Serial.print((float)(counters[i]/calls[i]));
      }
      counters[i] = 0;
      calls[i] = 0;
    }
    Serial.print(",");
    Serial.println(totalCalls);
    totalCalls = 0;
  } 
}
//*****************************************************************************
void loop() { 
  startTimer();
  NMEA2000.ParseMessages();
  endTimer(0);
// Only on demand as it causes startup to take time to complete
// listDevices.list();
  startTimer();
  temperature.read();
  endTimer(1);
  startTimer();
  temperature.output();
  endTimer(2);
  startTimer();
  modbus.read();
  endTimer(3);
  startTimer();
  modbus.output();
  endTimer(4);
  startTimer();

  logbook.log();
  endTimer(5);
//  logbook.demoMode();
  startTimer();
  CheckCommand();
  endTimer(6);
  startTimer();
#ifndef USE_INTERRUPT
  if ( checkPress() ) {
    Serial.println("Button Being pressed");
    display.nextPage();
  }
  endTimer(7);
  startTimer();
#endif
  display.update(lastButtonRelease);
  endTimer(8);
}

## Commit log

2021-11-06 Added ESP32Can pcb
    [ESP32CanBoard.kicad_pcb, ESP32CanBoard.sch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]
2021-11-12 Just before switching away from ESP32 ADC
    [ESP32CanBoard.kicad_pcb, ESP32CanBoard.sch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]
2021-11-15 Started work on ui for eink devices
2021-11-17 Working version served from flash disk
    [ESP32CanBoard.kicad_pcb]
2021-11-21 Added admin interface, fixed esp32 panic
2021-12-15 Added 24h history for pressure and logbook recording to flash
2021-12-29 Added Logging, fixed dome bugs with a read feed of packets
    [main.cpp]
2022-07-13 New board, moved bme280 to CanPressure board
    [ESP32CanBoard.kicad_pcb, ESP32CanBoard.sch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]
2022-07-15 New board operational using Modbus BatterySensors and CanPressure board
    [ESP32CanBoard.sch]
2022-07-15 Fixed display
    [DisplayBoxCase.scad, ESP32CanBoard.sch]
2022-07-16 NMEA2000 ESP does not set pins correctly as documented where there are libraries building
    [main.cpp]
2022-07-18 Added display pages and fixed ui
    [main.cpp]
2022-07-20 added time display and stopped listing devices on start
2022-11-17 Added 3.7 Waveshare eink display
    [BatteryMonitor.kicad_pcb, BatteryMonitor.sch]
2023-01-01 Adapted to new modbus shunt modules and tested over 10m wire
    [ESP32CanBoard.sch]
2023-02-02 Added TFT display module, and made Modbusmaster non blocking
    [ESP32CanBoard.sch]
2023-02-07 save after ide crash
    [main.cpp]
2023-04-09 Added polar calculations for display
    [ESP32CanBoard.sch]
